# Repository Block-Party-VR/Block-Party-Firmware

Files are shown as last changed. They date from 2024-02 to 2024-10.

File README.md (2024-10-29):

# Block Party

Stack blocks in real life. See them stack in VR.
Play with blocks in VR. See them change in real life.
If you’re feeling brave, enter the doll house.

Virtual reality can be a powerful tool to connect the physical world and the digital world and connect people in different locations.
However, many VR experiences today are limited to the digital world.
Many multi-user VR experiences place all users into the same digital world and people in the VR headset are cut off from the physical world.

Block Party uses an asymmetric experience to connect a person using a VR headset with a person without a headset.
The person without a headset interacts with physical blocks on a physical board while the person in the VR headset interacts with digital blocks on a digital board.
When the physical user places a physical block on the physical board, the VR user sees a block in the corresponding location on the digital board.
When the physical user removes a block from the board, the corresponding digital block disappears for the VR user.
When the VR user hovers over or picks up a digital cube, the corresponding physical cube changes color to show the physical user what the VR user is doing.

## Setup
### Repository Setup
When the repository is first cloned you will need to initialize all of its submodules. 

In the terminal type: `git submodule update --init --recursive` which will initalize all of the submodules.

### Board Assemble
#### Parts List
- Foam core (scavenged)
- (4) Thor labs boxes (scavenged)
- (1) ESP32
- (1) breadboard
- copper tape
- (9) magnets
- (9) 10k resistors
board documentation can be found int he `documentation` directory.

### Cube Assembly
#### Parts List
- 3D printed case and cover (stl files are in the documentation folder)
- WS2812B LED (1 strip of 2 LEDs)
- (1) 10k resistor
- copper tape
- (2) magnets
- Kapton tape
- black electrical tape to mark the bottom
wiring diagram for the cube is in the `documentation` directory.

### Hardware Required
- Meta Quest headset. The included Unity project uses SDKs for Android so other Android-based headsets may work, but have not been tested.
- The physical board and physical blocks
- Two USB power sources to run the physical board. One for the LEDs and one for the sensors detecting where the blocks are.

### Software Dependencies
#### Unity
- [`the Singularity`](https://github.com/VRatMIT/TheSingularity-Unity)
- Meta Presence Platform: hand tracking, pokable item, interaction, hand-poke interaction, synthetic hands, grab interaction, hand-poke limiter, pass-through
- Unity package: [DOTween](https://assetstore.unity.com/packages/tools/animation/dotween-hotween-v2-27676)

#### Board
- Adafruit’s Neopixel library
- Arduino libraries

### Bluetooth Module
On v0.1 of the board, a seperate bluetooth module (HC-05) is being used for bluetooth. This module needs to be programmed when first plugged in. To program the module, disconnect it from power and hold the "EN" button on the module. (The button should be the only button on the HC-05 module). While still holding down the button, reconnect the module to the ESP32. Let go of the button and then press the ESP32's reset button. Wait 5 seconds while still holding down the "EN" button on the module, then release the button, power cycle the module, and you're done.

## Run
- Power up the board and pair it with the headset over bluetooth.
- Build and load the Unity project to the headset.
- The first time the Unity project starts on the headset, you will receive a request for Bluetooth permissions. Grant the permission and restart the app. The restart is required after permissions are granted due to current limitations on `the Singularity`.
- After restarting the app, the app should automatically connect to the physical board and respond to blocks being placed on the physical board.
- Enjoy the connection between the digital and physical world.

## Unity interactions

### Interacting with the digital blocks
Once the cube has been placed on the board a cube in VR will appear.
The VR user can poke and pickup the digital blocks which will be indicated in real life by changing the colors of the blocks. Poking will change the block color to blue and picking it up will change it to red.

### Passthrough mode
The user can activate passthrough mode inside the app to see the physical board and the digital board at the same time.

### Dollhouse mode
When the dollhouse mode is activated, the digital blocks are increased in size and the VR user is moved to the center square of the board.
Note that a physical cube on the center square of the board will not appear in the digital world.

## Board Command Docs
The board contains an ESP32 that uses bluetooth serial to send the state of the board and receive commands.

### Command Name: `BoardState`
Command Number: `0`

Format Example: `!0,X1,X2,X3,X4,X5,X6,X7,X8,X9;`

Description: This command is sent when the board state changes and describes how the board is populated.

| X1 X2 X3 |

| X4 X5 X6 |

| X7 X8 X9 |

0 corresponds with the command type. The command number for BoardState is 0.
X1 corresponds with board spot X1, and so on. The value in each of the spots indicates how many cubes are in that spot.
IE: If X1 where 3, then there would be 3 cubes in the top left spot.

If you would like to get the board state, you can send !0; to the ESP32 and it will respond with the current board state. Otherwise, the ESP32 will send the board state whenever it changes.

### Command Name `Ping`
Command Number: `1`

Format Example: `!1;`

Description: This command is sent to the ESP32 to check if it is still connected. The ESP32 will respond with `!1;` if it is still connected.

### Command Name: `SetStackColor`
Command Number: `2`

Format Example: `!2,StackNumber,Red1,Green1,Blue1,Red2,Green2,Blue2,...REDX,GREENX,BLUEX;`

Description Set the colors for one of the stacks.
- 2 corresponds with the command type. The command number for SetStackColor is 2.
- StackNumber corresponds with the stack number you want to set the colors for. See `BoardState` description for stack numbers.
- Red1, Green1, Blue1 correspond with the color of the first cube in the stack and so on. These values can be between 0-255.
You can add as many colors as you want, but they wont display if the corresponding cube doesn't physically exist.

### Command Name: `GoToIdle`
Command Number: `3`

Format Example `!3;`

Description: This command will tell the ESP32 to re-enable its idle animation. It will respond with a `!3;` when it recieves this command.

## Shout-Outs
- Thank you to all the organizers at Reality Hack and the Hardware track.
- Lucas De Bonet for creating `the Singularity` which allowed us to connect the board to Quest headsets.
- Mentor Mark Steelman for showing us the value (and complications) of runtime list creation and showing us how to make an in-editor button for debugging.
- Fellow Reality Hack hacker Sean Feeser for help with debugging.
- Juan Gil for helping us 3D print.

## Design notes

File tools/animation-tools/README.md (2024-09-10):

# Setup
In order to run this tool follow these steps:

1. ensure you're using python 3.12+. You can verify this by running 
```
python --version
``` 
in a terminal.

2. Inside of a terminal in the 
```
tools/animation-tools
``` 
folder, run: 
```
python -m venv venv
```
 to create your virtual environment.

3. Now activate the virtual environment. In powershell run 
```
venv\Scripts\activate
```
You may need to fix permission issues if this is your first time using a virtual environment. For git bash just run: 
```
source venv/Scripts/activate
```
4. Run 
```
pip install -r requirements.txt
```

# How to Use
The animation tool was made to allow anyone to easily create animaitons without much practice. You can create a sequence of frames in the studio, export them and then copy them over to the firmware

## Creating a Frame
When you first run the program the window will look like this:

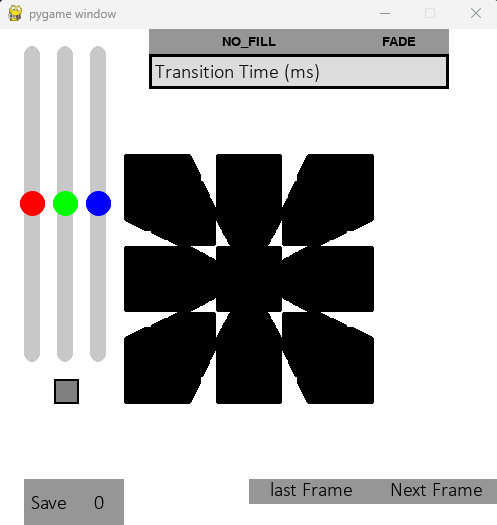
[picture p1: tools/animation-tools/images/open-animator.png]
Startup


### Rotating the view
Press and hold the middle mouse button and move around the mouse to rotate the view.

### Changing Cube Colors
Click on a cube to select it. Selected cubes will be highlighted in red. All selected cubes will be set to the current color picker color. You can deselect a block by clicking on it again.

The color picker consists of 3 sliders on the left of the screen. A preview of the color is in a small box underneath the sliders. Move the sliders around to change colors.

### Fill Options
Fill options tell the board how to color cubes which are set to black in the animator. There are four options:

#### No Fill
Cubes that are set to black will be off

#### Closest Color
Cubes that are set to black will become the same color as their closest colored neighbor

#### Linear
Cubes that are set to black will become a distance weighted average of all of the colored cubes

#### Square
Same as linear, but the distance weighting is squared. This means a cube that's twice as far away will have only 1/4 the effect.

### Fade options
The fade options tell the board how to transition between frames

#### Snap
The colors will remain constant until the delay time for the current frame has passed. At that point, the frame will immediatly switch to the next frame.

#### Fade
The colors will linearly transition from one frame to the next. This often results in very interesting colors and patterns emerging.

### Creating more than one frame
An animation isn't really an animation with only one frame. You can add more frames to your animation with the "Next Frame" button. This will create a new frame for you to edit. You'll also notice the frame counter above the next frame button will go up. That shows you the current frame number that you're editing. You can view previous frames but clicking on the last frame button.

### Exporting your Animation
Now that you're done creating your lovely animation you can export it! Click the save button and C++ code will automatically be generated which describes all of the frames you just created. The code is saved in output.txt in the animation-tools folder. How to use that code is beyond the scope of this README. Reach out to Quinn for more instruction.

# Future features
Eventually I would like to add the ability to send the animations directly to the board without having to mess with the firmware at all. This will take a pretty big rework though.

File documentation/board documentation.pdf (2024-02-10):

# Block Party by Platypods

# electrical and mechanical initial design

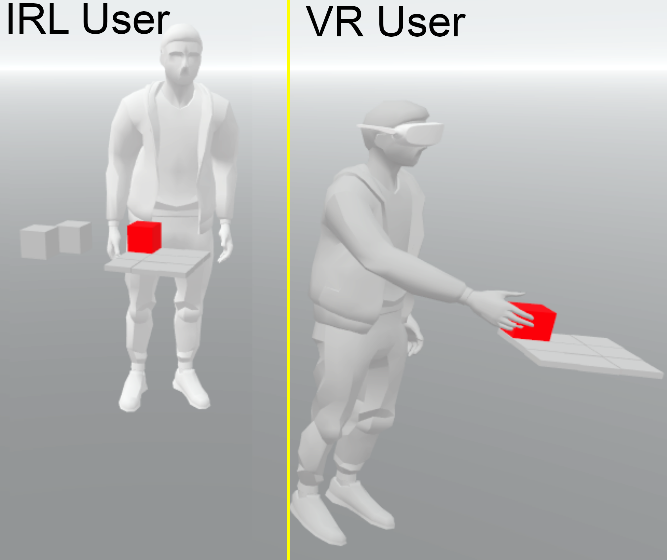
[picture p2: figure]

### Enables people in both VR and IRL to interact simultaneously with

real world objects and digital twin VR objects.

The functional idea is: to have a grid of 3x3, and use resistors to sense where blocks

populate the board, with stacked blocks reducing measured resistance. The leds

inside the blocks are addressable by the ESP32, so they may light up in IRL when

manipulated in VR.

The ESP32 sends and receives data via the MIT developed Singularity plugin for

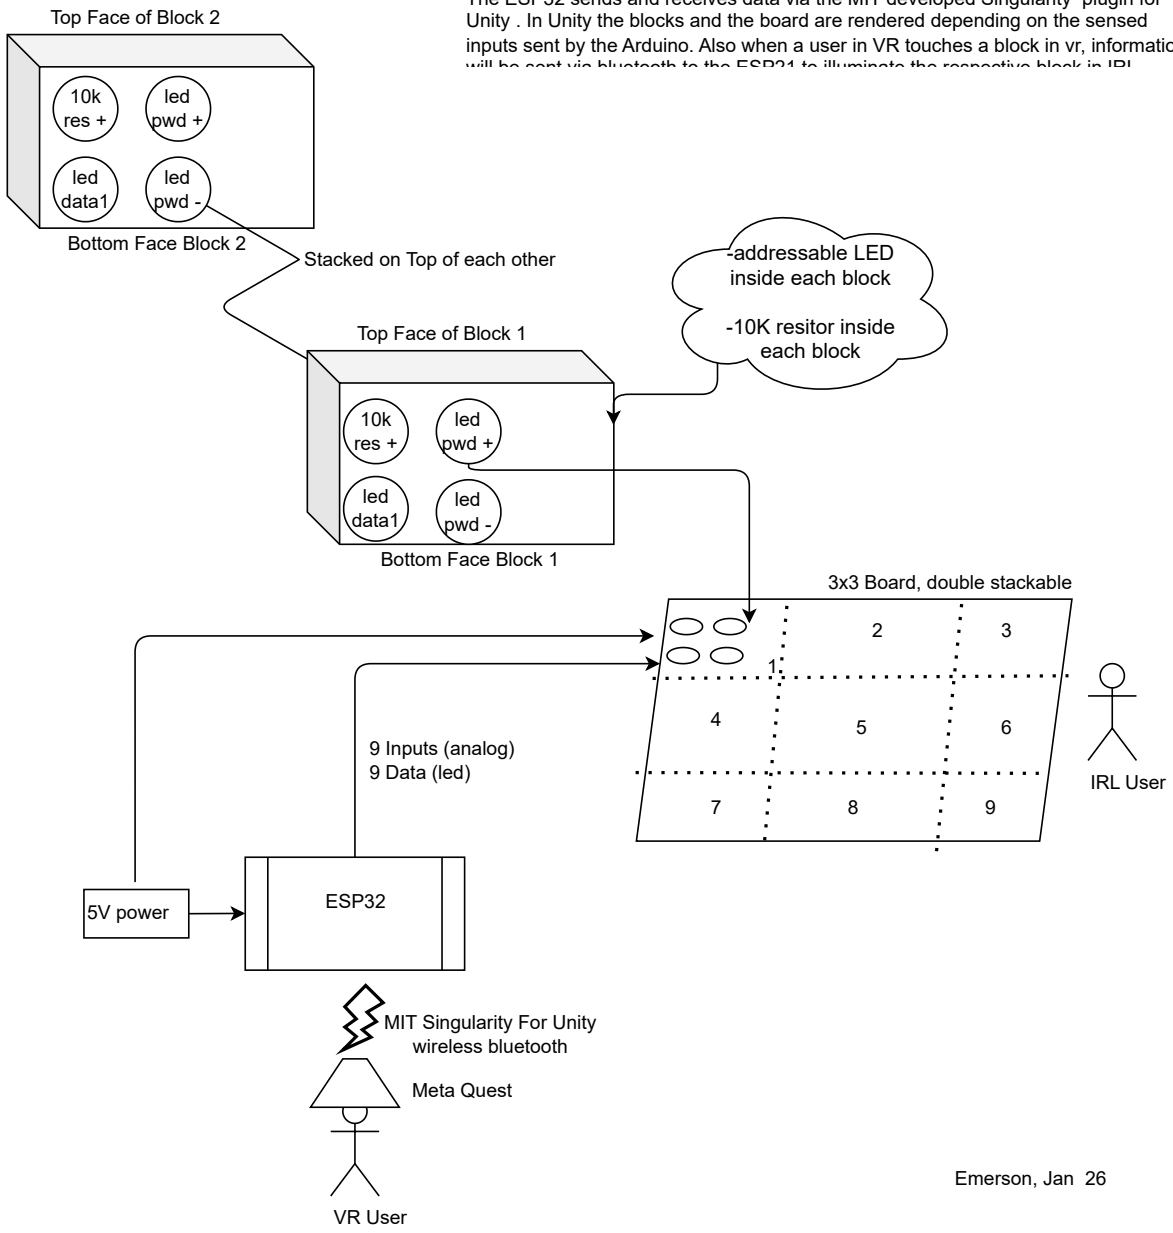
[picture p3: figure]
10k res +; led pwd +; led data1; led pwd -; Bottom Face Block 1; Top Face of Block 1; Bottom Face Block 2; Top Face of Block 2; Stacked on Top of each other; ESP32; 9 Inputs (analog) 9 Data (led); 3x3 Board, double stackable; MIT Singularity For Unity wireless bluetooth; VR User; Meta Quest; Emerson, Jan 26; 5V power; IRL User; -addressable LED inside each block; -10K resitor inside each block

Unity . In Unity the blocks and the board are rendered depending on the sensed inputs sent by the Arduino. Also when a user in VR touches a block in vr, information will be sent via bluetooth to the ESP21 to illuminate the respective block in IRL

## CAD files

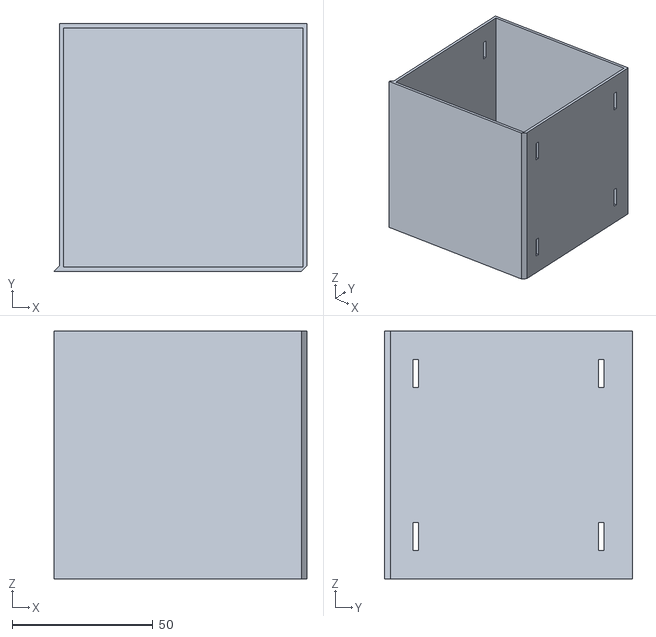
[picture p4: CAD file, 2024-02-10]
documentation/stack cube.stl
89.9 x 88.0 x 88.0

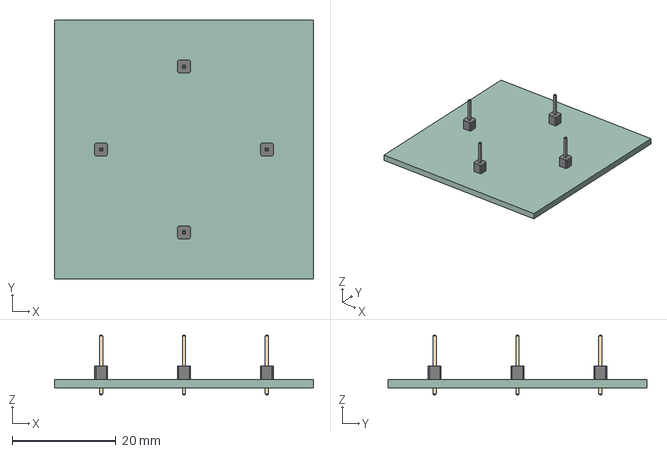
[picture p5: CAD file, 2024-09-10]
Schematics/Block-Party/PCB Models/Block-Party-Cube-Top-Board.step
50.0 x 50.0 x 11.5 mm
PinHeader_1x01_P254mm_Vertical x 4
Block-Party-Cube-Top-Board PCB

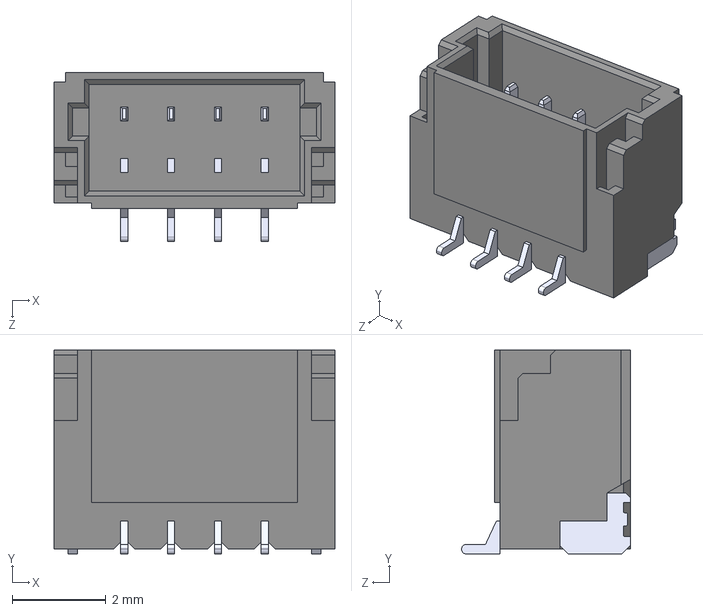
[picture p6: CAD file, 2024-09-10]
Schematics/PCB Components/adafruit-jst-4328/4328.step
6.00 x 4.35 x 3.60 mm

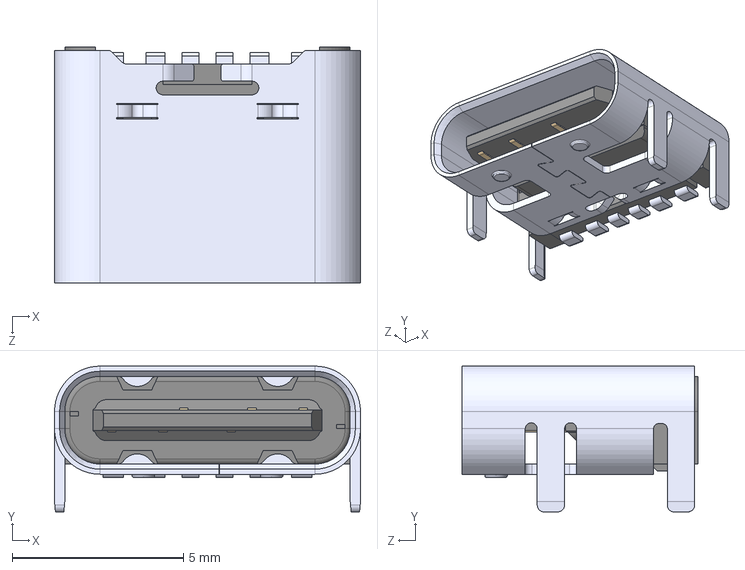
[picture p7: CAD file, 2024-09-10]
Schematics/PCB Components/UJC-HP-3-SMT-TR/UJC-HP-3-SMT-TR.step
8.94 x 4.26 x 6.90 mm

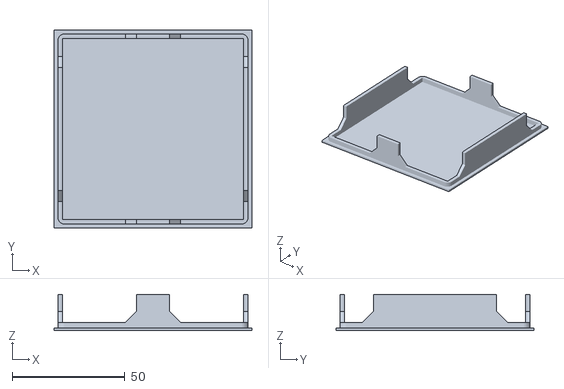
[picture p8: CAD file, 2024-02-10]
documentation/Stack_Cube_Lid.stl
88.0 x 88.0 x 16.1

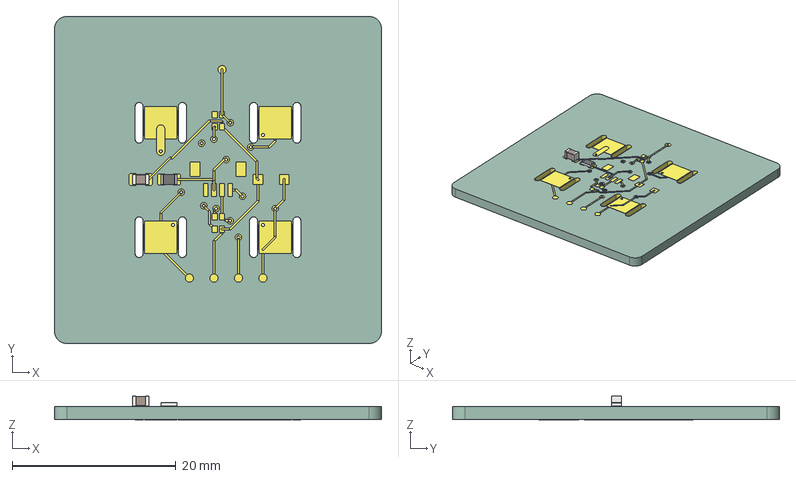
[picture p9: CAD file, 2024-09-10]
Schematics/Block-Party/PCB Models/Block-Party-Bottom-PCB.step
40.0 x 40.0 x 2.94 mm
C_0805_2012Metric
R_0805_2012Metric
Block-Party-Bottom-Board_track_1
Block-Party-Bottom-Board_track_2
Block-Party-Bottom-Board_track_3
Block-Party-Bottom-Board_track_4
Block-Party-Bottom-Board_track_5
Block-Party-Bottom-Board_track_6
Block-Party-Bottom-Board_track_7
Block-Party-Bottom-Board_track_8
Block-Party-Bottom-Board_track_9
Block-Party-Bottom-Board_track_10
Block-Party-Bottom-Board_track_11
Block-Party-Bottom-Board_track_12
Block-Party-Bottom-Board_track_13
Block-Party-Bottom-Board_track_14
Block-Party-Bottom-Board_track_15
Block-Party-Bottom-Board_track_16
Block-Party-Bottom-Board_track_17
Block-Party-Bottom-Board_track_18
Block-Party-Bottom-Board_track_19
Block-Party-Bottom-Board_track_20
Block-Party-Bottom-Board_track_21
Block-Party-Bottom-Board_track_22
Block-Party-Bottom-Board_track_23
Block-Party-Bottom-Board_track_24
Block-Party-Bottom-Board_track_25
Block-Party-Bottom-Board_track_26
Block-Party-Bottom-Board_track_27
Block-Party-Bottom-Board_track_28
Block-Party-Bottom-Board_track_29
Block-Party-Bottom-Board_track_30
Block-Party-Bottom-Board_track_31
Block-Party-Bottom-Board_track_32
Block-Party-Bottom-Board_track_33
Block-Party-Bottom-Board_track_34
Block-Party-Bottom-Board_track_35
Block-Party-Bottom-Board_track_36
Block-Party-Bottom-Board_track_37
Block-Party-Bottom-Board_track_38
Block-Party-Bottom-Board_track_39
Block-Party-Bottom-Board_track_40
Block-Party-Bottom-Board_track_41
Block-Party-Bottom-Board_track_42
Block-Party-Bottom-Board_track_43
Block-Party-Bottom-Board_track_44
Block-Party-Bottom-Board_track_45
Block-Party-Bottom-Board_track_46
Block-Party-Bottom-Board_track_47
Block-Party-Bottom-Board_track_48
Block-Party-Bottom-Board_track_49
Block-Party-Bottom-Board_track_50
Block-Party-Bottom-Board_track_51
Block-Party-Bottom-Board_track_52
Block-Party-Bottom-Board_track_53
Block-Party-Bottom-Board_track_54
Block-Party-Bottom-Board_track_55
Block-Party-Bottom-Board_track_56
Block-Party-Bottom-Board_track_57
Block-Party-Bottom-Board_track_58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

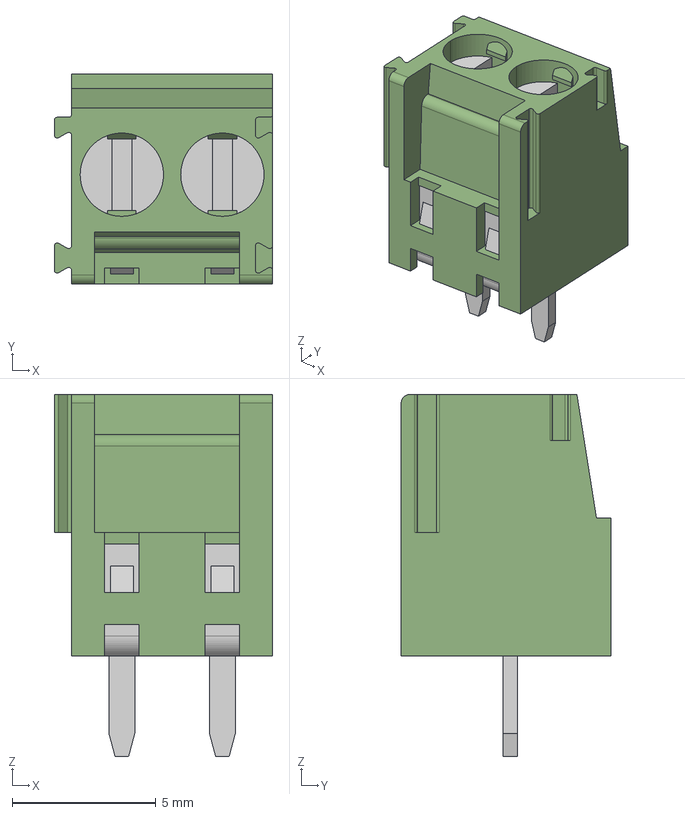
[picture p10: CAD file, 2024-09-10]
Schematics/PCB Components/2p 3.5mm terminal block/691214110002S.step
7.60 x 7.30 x 12.6 mm

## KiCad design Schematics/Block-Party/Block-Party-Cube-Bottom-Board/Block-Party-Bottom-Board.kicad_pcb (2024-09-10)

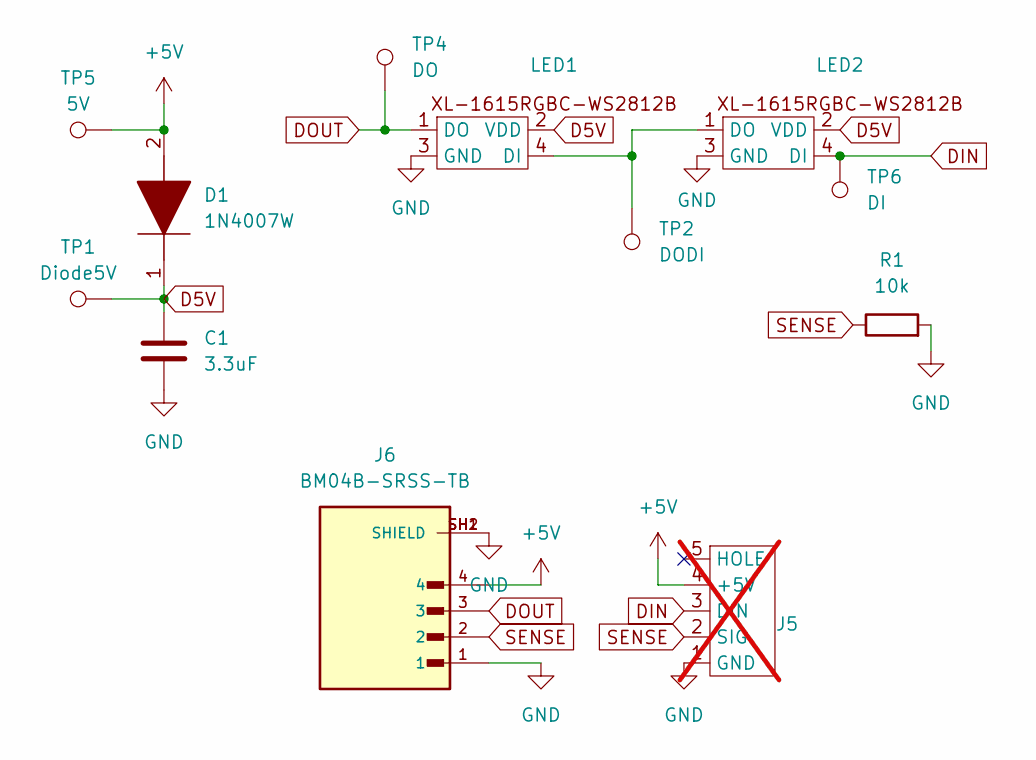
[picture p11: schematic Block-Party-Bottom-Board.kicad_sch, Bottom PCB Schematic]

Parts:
C1: 3.3uF; C_0805_2012Metric; Manufacturer_Part_Number CS2012X5R475K500NRE
D1: 1N4007W; Manufacturer_Part_Number 1N4007W
J5: Bottom Block Connector; not fitted
J6: BM04B-SRSS-TB; ADAFRUIT_4328; PARTREV 23/3/21
LED1: XL-1615RGBC-WS2812B; Manufacturer_Part_Number Quinn_lib:XL-1615RGBC-WS2812B
LED2: XL-1615RGBC-WS2812B; Manufacturer_Part_Number XINGLIGHT XL-1615RGBC-WS2812B
R1: 10k; R_0805_2012Metric; Manufacturer_Part_Number AC0805FR-0710KL
TP1: Diode5V; TestPoint_Pad_D1.0mm
TP2: DODI; TestPoint_Pad_D1.0mm
TP4: DO; TestPoint_Pad_D1.0mm
TP5: 5V; TestPoint_Pad_D1.0mm
TP6: DI; TestPoint_Pad_D1.0mm

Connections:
+5V: D1.2, J5.4 (+5V), J6.4, TP5.1
D5V: C1.1, D1.1, LED1.2 (VDD), LED2.2 (VDD), TP1.1
DIN: J5.3 (DIN), LED2.4 (DI), TP6.1
DOUT: J6.3, LED1.1 (DO), TP4.1
GND: C1.2, J5.1 (GND), J6.1, J6.SH1 (SHIELD), J6.SH2 (SHIELD), LED1.3 (GND), LED2.3 (GND), R1.2
unnamed: LED1.4 (DI), LED2.1 (DO), TP2.1
SENSE: J5.2 (SIG), J6.2, R1.1

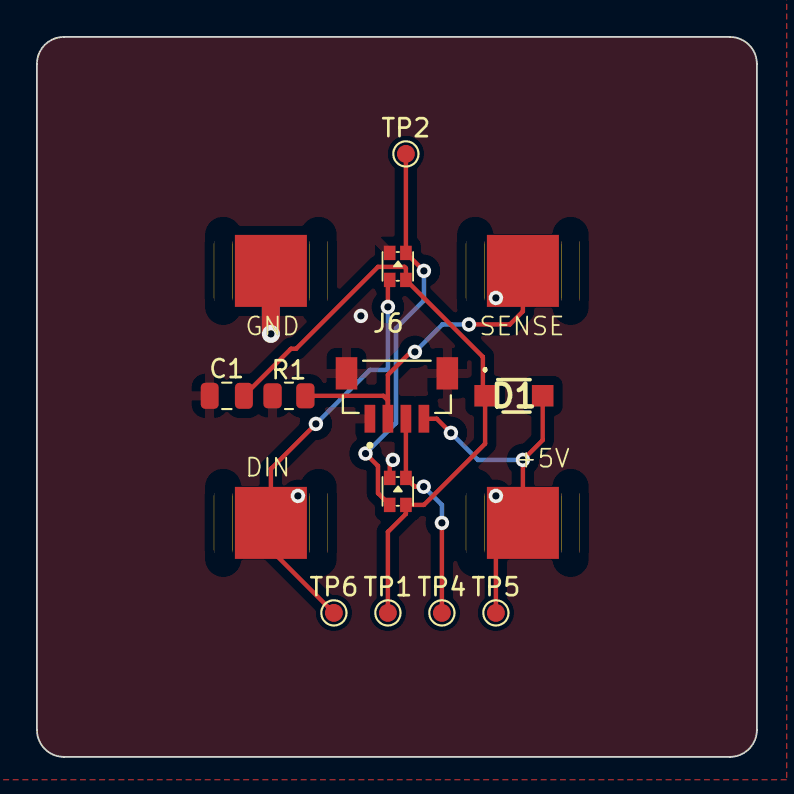
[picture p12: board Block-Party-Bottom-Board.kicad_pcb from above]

Board: 2 copper layers, 40.0 x 40.0 mm, 12 parts (0 on the bottom side), 7 nets.

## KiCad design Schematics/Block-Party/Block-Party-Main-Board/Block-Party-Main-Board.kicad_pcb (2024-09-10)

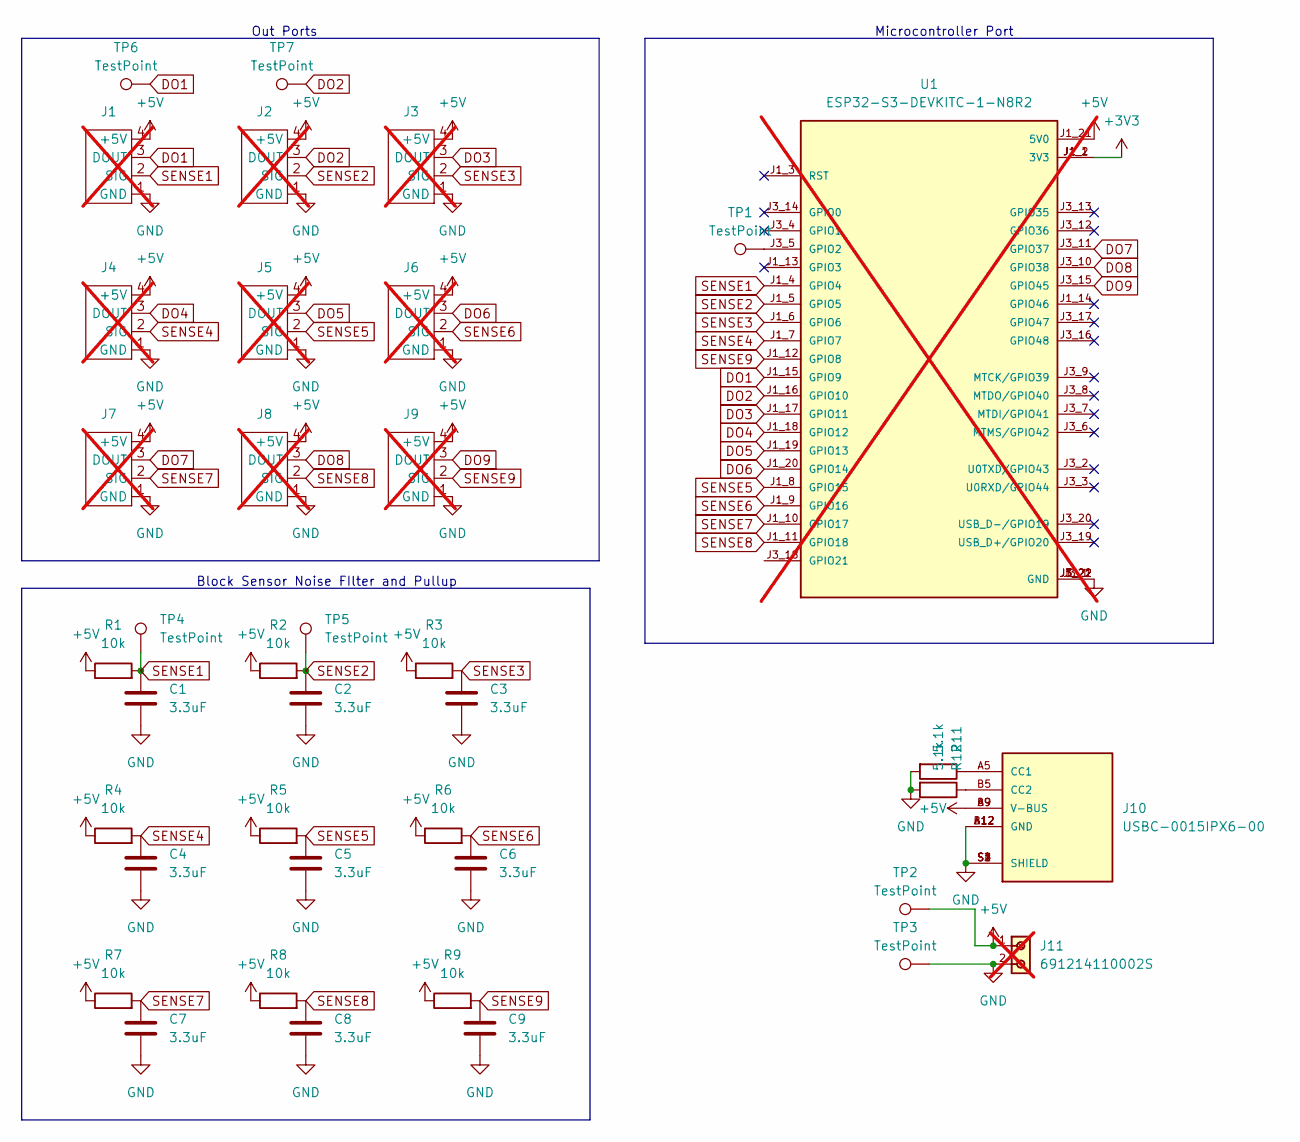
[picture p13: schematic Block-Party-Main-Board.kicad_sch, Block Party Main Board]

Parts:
C1, C2, C3, C4, C5, C6, C7, C8, C9: 3.3uF; C_0805_2012Metric; PART-NUMBER CS2012X5R475K500NRE
J1, J2, J3, J4, J5, J6, J7, J8, J9: Top Block Connector; not fitted
J10: USBC-0015IPX6-00; USB_C-0015IPX6-00; PARTREV 04/30/2020
J11: 691214110002S; PART-NUMBER 691214110002S; not fitted
R1, R2, R3, R4, R5, R6, R7, R8, R9: 10k; R_0805_2012Metric; PART-NUMBER AR05DTD1002
R11, R12: 5.1k; R_0805_2012Metric; PART-NUMBER CR0805-FX-5101ELF
TP1, TP2, TP3, TP4, TP5, TP6, TP7: TestPoint; TestPoint_Pad_D2.0mm
U1: ESP32-S3-DEVKITC-1-N8R2; XCVR_ESP32-S3-DEVKITC-1-N8R2; PARTREV V1; not fitted

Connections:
+3V3: U1.J1_1 (3V3), U1.J1_2 (3V3)
+5V: J1.4 (+5V), J2.4 (+5V), J3.4 (+5V), J4.4 (+5V), J5.4 (+5V), J6.4 (+5V), J7.4 (+5V), J8.4 (+5V), J9.4 (+5V), J10.A9 (V-BUS), J10.B9 (V-BUS), J11.1, R1.1, R2.1, R3.1, R4.1, R5.1, R6.1, R7.1, R8.1, R9.1, TP2.1, U1.J1_21 (5V0)
DO1: J1.3 (DOUT), TP6.1, U1.J1_15 (GPIO9)
DO2: J2.3 (DOUT), TP7.1, U1.J1_16 (GPIO10)
DO3: J3.3 (DOUT), U1.J1_17 (GPIO11)
DO4: J4.3 (DOUT), U1.J1_18 (GPIO12)
DO5: J5.3 (DOUT), U1.J1_19 (GPIO13)
DO6: J6.3 (DOUT), U1.J1_20 (GPIO14)
DO7: J7.3 (DOUT), U1.J3_11 (GPIO37)
DO8: J8.3 (DOUT), U1.J3_10 (GPIO38)
DO9: J9.3 (DOUT), U1.J3_15 (GPIO45)
GND: C1.1, C2.1, C3.1, C4.1, C5.1, C6.1, C7.1, C8.1, C9.1, J1.1 (GND), J2.1 (GND), J3.1 (GND), J4.1 (GND), J5.1 (GND), J6.1 (GND), J7.1 (GND), J8.1 (GND), J9.1 (GND), J10.A12 (GND), J10.B12 (GND), J10.S1 (SHIELD), J10.S2 (SHIELD), J10.S3 (SHIELD), J10.S4 (SHIELD), J11.2, R11.2, R12.2, TP3.1, U1.J1_22 (GND), U1.J3_1 (GND), U1.J3_21 (GND), U1.J3_22 (GND)
unnamed: J10.A5 (CC1), R11.1
unnamed: J10.B5 (CC2), R12.1
unnamed: TP1.1, U1.J3_5 (GPIO2)
SENSE1: C1.2, J1.2 (SIG), R1.2, TP4.1, U1.J1_4 (GPIO4)
SENSE2: C2.2, J2.2 (SIG), R2.2, TP5.1, U1.J1_5 (GPIO5)
SENSE3: C3.2, J3.2 (SIG), R3.2, U1.J1_6 (GPIO6)
SENSE4: C4.2, J4.2 (SIG), R4.2, U1.J1_7 (GPIO7)
SENSE5: C5.2, J5.2 (SIG), R5.2, U1.J1_8 (GPIO15)
SENSE6: C6.2, J6.2 (SIG), R6.2, U1.J1_9 (GPIO16)
SENSE7: C7.2, J7.2 (SIG), R7.2, U1.J1_10 (GPIO17)
SENSE8: C8.2, J8.2 (SIG), R8.2, U1.J1_11 (GPIO18)
SENSE9: C9.2, J9.2 (SIG), R9.2, U1.J1_12 (GPIO8)

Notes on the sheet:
Out Ports
Microcontroller Port
Block Sensor Noise FIlter and Pullup

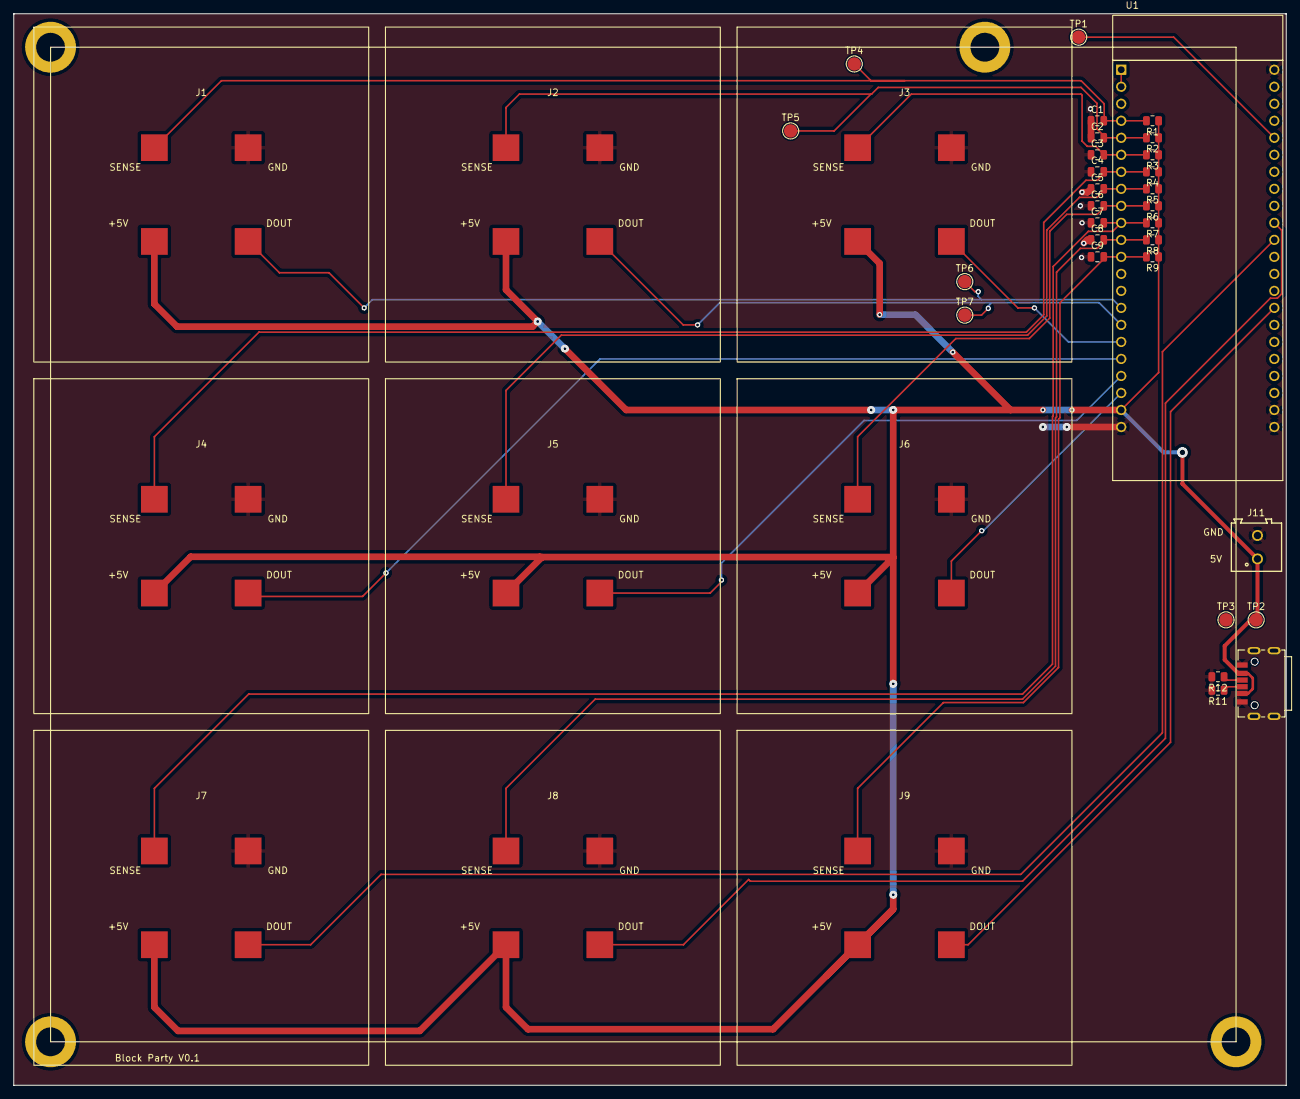
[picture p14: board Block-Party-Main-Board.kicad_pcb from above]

Board: 2 copper layers, 190.0 x 160.0 mm, 39 parts (0 on the bottom side), 24 nets.

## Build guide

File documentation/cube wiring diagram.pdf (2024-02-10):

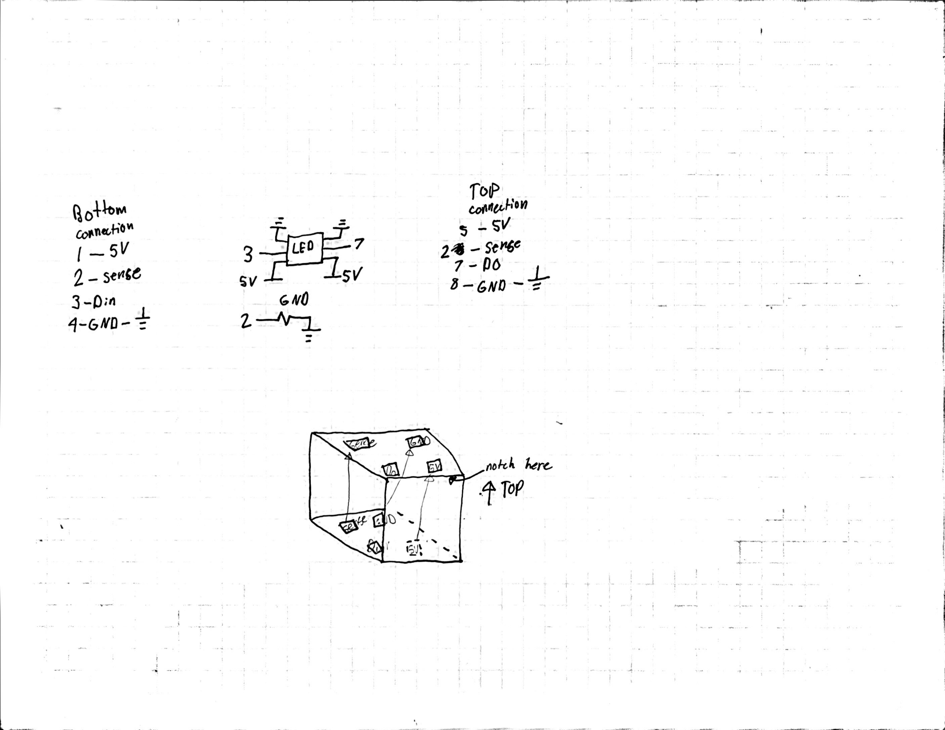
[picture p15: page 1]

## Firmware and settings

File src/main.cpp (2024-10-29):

// Other peoples libraries
#include <Arduino.h>
#include <BluetoothSerial.h>
#include <FreeRTOS.h>
#include <Adafruit_NeoPixel.h>
#include <chrono>
#include <array>

// Static Defines
#include "PINOUT.h"
#include "BOARD-DEFINITIONS.h"
#include "COMMANDS.h"

// project specific libraries
#include "BluetoothSerial.h"
#include "SerialMessage.h"
#include "GlobalPrint.h"
#include "CommandHandler.h"

#include "BoardManager.h"
#include "BoardDriver.h"
#include "BoardTypes.h"

#include "Animator.h"
#include "TestFrames.h"
#include "Animation.h"

// --------------------------------------------------
// ----------------- VARIABLES ----------------------
// --------------------------------------------------
TaskHandle_t updateCommunicaitonTask;
TaskHandle_t updateBoardTask;

// WARNING! This array size should always be equal to the number of entries in it!!
std::array<std::vector<AnimationFrame>*, 2> animations = {
  &RisingCubes::rising,
  &RotatingCubes::rotating,
};

CommandHandler commandHandler{};

// BluetoothSerial SerialBT;
// BluetoothSerialMessage serialMessageBT(&SerialBT);
SerialMessage<SERIAL_CHAR_LENGTH, SERIAL_ARG_LENGTH> serialMessage(&Serial);

Adafruit_NeoPixel pixelController{BOARD_HEIGHT*2, STACK1_LED_PIN, NEO_GRB + NEO_KHZ800};

Animator<BOARD_DIMENSIONS> animator{};
BoardDriver<BOARD_WIDTH*BOARD_LENGTH> boardDriver{stacks, pixelController};
BoardManager<BOARD_DIMENSIONS> boardManager{boardDriver, animator};
// --------------------------------------------------
// ----------------- FUNCTIONS ----------------------
// --------------------------------------------------
/**
 * @brief Send programming commands to the serial to bluetooth adapter so 
 * it is set up as expected for the VR headset
 * @post the serial baud rate will be set to 9600
 */
void SetupBluetoothModule(){
  Serial.begin(38400);
  Serial.print("AT+UART=9600,0,0\r\n"); // set baud rate to 9600
  delay(100);

  Serial.print("AT+NAME=blockPartyBT-v01\r\n"); // set name to blockPartyBT-v0.1
  delay(100);

  Serial.print("AT+PSWD=1234\r\n"); // set password to 1234
  delay(100);

  Serial.print("AT+ROLE=0\r\n"); // set to slave
  delay(100);

  // exit at mode and go into pairing mode
  Serial.print("AT+INIT\r\n");
  Serial.begin(9600);
  delay(100);
}

void printBoardState(){
  GlobalPrint::Print("!0,");
  String boardString;
  boardManager.Board2StackString(boardString);
  GlobalPrint::Print(boardString);
  GlobalPrint::Println(";");
}

void SetStackColor(uint32_t * args, uint32_t argsLength){
  uint32_t stackNum = args[0];
  uint32_t X_COORD{stackNum};
  while(X_COORD > BOARD_DIMENSIONS.x - 1){
    X_COORD -= BOARD_DIMENSIONS.x;
  }
  uint32_t Y_COORD{(stackNum - X_COORD) / BOARD_DIMENSIONS.y};
  Serial.println("StackNum: " + String(stackNum));
  Serial.println("X: " + String(X_COORD) + " Y: " + String(Y_COORD));
  uint32_t numColors = (argsLength - 1) / 3;

  // nothing to do if no colors were given
  if(numColors == 0){
    return;
  }
  
  Serial.println("Num Colors: " + String(numColors));
  V3D<uint32_t> colors[numColors];
  
  for(int i = 0; i < numColors; i++){
    uint32_t red = args[1 + (i * 3)];
    uint32_t green = args[2 + (i * 3)];
    uint32_t blue = args[3 + (i * 3)];
    colors[i] = V3D<uint32_t>{red, green, blue};
    Serial.println("Color: " + String(red) + "," + String(green) + "," + String(blue));
  }
  boardManager.SetColumnColors(V3D<uint32_t>{X_COORD, Y_COORD, BOARD_TYPES::PLANE_NORMAL::Z}, colors, numColors);
}

// command handling functions
CommandHandler::CommandStatus BoardStateCommandHandler(uint32_t * /*args*/, uint32_t /*argsLength*/){
  printBoardState();
  return CommandHandler::CommandStatus::SUCCESS;
}

CommandHandler::CommandStatus PingCommandHandler(uint32_t * /*args*/, uint32_t /*argsLength*/){
  GlobalPrint::Println("!" + String(Commands::PING) + ";");
  return CommandHandler::CommandStatus::SUCCESS;
}

CommandHandler::CommandStatus SetColorCommandHandler(uint32_t * args, uint32_t argsLength){
  GlobalPrint::Println("!2;");
  animator.isEnabled = false;
  V3D<uint32_t> black{};
  boardManager.FillColor(black);
  SetStackColor(args, argsLength);
  return CommandHandler::CommandStatus::SUCCESS;
}

CommandHandler::CommandStatus GoToIdleCommandHandler(uint32_t * /*args*/, uint32_t /*argsLength*/){
  GlobalPrint::Println("!3;");
  animator.isEnabled = true;
  return CommandHandler::CommandStatus::SUCCESS;
}



// --------------------------------------------------
// ----------------- FREERTOS TASKS -----------------
// --------------------------------------------------
void UpdateCommunication(void * params){
  Serial.println("Spawning UpdateCommunication task");
  for(;;){
    // DO serial processing
    serialMessage.Update();
    if(serialMessage.IsNewData()){
      // We reinterpret cast the args to a uint32_t pointer because we know that the args will always be positive
      commandHandler.ProcessCommand(reinterpret_cast<uint32_t *>(serialMessage.GetArgs()), serialMessage.GetPopulatedArgs());
      serialMessage.ClearNewData();
    }
    // serialMessageBT.Update();
    // if(serialMessageBT.IsNewData()){
    //   commandHandler.ProcessCommand(reinterpret_cast<uint32_t *>(serialMessage.GetArgs()), serialMessage.GetPopulatedArgs());
    //   serialMessage.ClearNewData();
    // }
    vTaskDelay(3);
  }
  Serial.println("UpdateCommunication task has ended unexpectedly!");

}

void UpdateBoard(void * params){
  Serial.println("Spawning UpdateBoard task");
  auto updateTickRate{std::chrono::milliseconds(8)};
  auto boardStateTimer{std::chrono::milliseconds(0)};
  auto boardStateMaxUpdatePeriod{std::chrono::milliseconds(34)}; // this is a little slower than 30fps
  unsigned long accurateTimer{millis()};
  auto changeAnimationTimer{std::chrono::milliseconds(0)};
  uint8_t currentAnimation{0};

  for(;;){
    auto actualTimePassed{std::chrono::milliseconds(millis() - accurateTimer)};
    accurateTimer = millis();

    if(boardStateTimer >= boardStateMaxUpdatePeriod && boardManager.HasBoardChanged()){
      printBoardState();
      boardManager.ClearBoardChanged();
      boardStateTimer = std::chrono::milliseconds(0);
    }

    if(changeAnimationTimer >= std::chrono::duration_cast<std::chrono::milliseconds>(std::chrono::minutes(1))){
      changeAnimationTimer = std::chrono::milliseconds(0);
      currentAnimation++;
      if(currentAnimation >= animations.size()){
        currentAnimation = 0;
      }
      animator.StartAnimation(animations[currentAnimation]);
    }

    animator.RunAnimation(actualTimePassed);
    boardManager.Update();

    boardStateTimer += actualTimePassed;
    changeAnimationTimer += actualTimePassed;
    vTaskDelay(updateTickRate.count());
  }
  Serial.println("UpdateBoard task has ended unexpectedly!");
}


// --------------------------------------------------
// ----------------- SETUP AND LOOP -----------------
// --------------------------------------------------

void setup() {
  // delay a little bit to get the serial monitor a chance to capture the next log messages.
  delay(1000);

  Serial.begin(9600);
  Serial.println("Beginning Setup");
  Serial.println("Configuring Bluetooth Adapter");
  SetupBluetoothModule();
  Serial.begin(9600);

  // Register all of our commands with the command handler
  commandHandler.RegisterCommand(Commands::BoardState, BoardStateCommandHandler);
  commandHandler.RegisterCommand(Commands::PING, PingCommandHandler);
  commandHandler.RegisterCommand(Commands::SetStackColors, SetColorCommandHandler);
  commandHandler.RegisterCommand(Commands::GoToIdle, GoToIdleCommandHandler);

  Serial.println("Configuring communication methods");
  serialMessage.Init(9600);
  // SerialBT.begin("blockPartyBT");
  xTaskCreate(UpdateCommunication, "UpdateCommunication", 10000, NULL, 0, &updateCommunicaitonTask);

  Serial.println("Beginning Board Initializaiton");
  boardManager.Init();
  animator.SetLoop(true);
  animator.StartAnimation(animations[0]);
  xTaskCreate(UpdateBoard, "UpdateBoard", 10000, NULL, 0, &updateBoardTask);

  Serial.println("Setup Complete");
}


void loop() {
  // delete the loop task because we don't use it
  vTaskDelete(NULL);
}

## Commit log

2024-02-10 Created bottom block schematic
    [Block-Party.kicad_pcb, Block-Party.kicad_sch]
2024-02-13 Created block party main board schematic
    [Block-Party-Main-Board.kicad_pcb, Block-Party-Main-Board.kicad_sch, Block-Party.kicad_pcb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]
2024-02-13 Added a usb power connector.
    [Block-Party-Main-Board.kicad_pcb, Block-Party-Main-Board.kicad_sch]
2024-02-13 Added additional components.
    [UJC-HP-3-SMT-TR.step]
2024-02-13 Finished touch up details for the bottom block board
    [Block-Party.kicad_pcb]
2024-02-16 Finished v1.0 of the PCBs
    [Block-Party-Bottom-PCB.step, Block-Party-Cube-Top-Board.kicad_pcb, Block-Party-Cube-Top-Board.kicad_sch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]
2024-03-23 Flipped the bottom pads to be the correct orientation
    [Block-Party.kicad_pcb]
2024-04-20 rearranged the schematic folders
    [Block-Party-Bottom-Board.kicad_pcb, Block-Party-Bottom-Board.kicad_sch]
2024-04-23 Revision 1.01 of the PCBs
    [4328.step, 691214110002S.step, Block-Party-Bottom-Board.kicad_pcb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]
2024-04-23 Found a good jst part number and updated the BOMs
    [Block-Party-Bottom-Board.kicad_pcb, Block-Party-Bottom-Board.kicad_sch, Block-Party-Cube-Top-Board.kicad_pcb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]
2024-04-29 Made the top and bottom PCB the same size
    [Block-Party-Bottom-Board.kicad_pcb, Block-Party-Cube-Top-Board.kicad_pcb]
2024-05-07 Added main board mounting holes
    [Block-Party-Main-Board.kicad_pcb]
2024-05-07 Added bottom pads to the bottom block PCB
    [Block-Party-Bottom-Board.kicad_pcb, Block-Party-Bottom-PCB.step]
2024-05-16 Updated micro configuration files to match the new micro we're using.
    [Block-Party-Bottom-Board.kicad_pcb, Block-Party-Bottom-Board.kicad_sch]
2024-06-07 Small tweaks and an update limiter for the esp32
    [Block-Party-Main-Board.kicad_pcb]
2024-06-10 Pulled the most up to date serial driver
2024-08-12 added v0.1 to the bluetooth module name
    If you have multiple bluetooth devices paired with the same name, the quest app only connects to the first one on the list. Adding the version number lets us keep multiple versions of the board paire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
2024-08-20 Added framework for users to edit the paltformio file for machine differences without uploading the changes to github.
2024-08-22 Refactoring how board control works
2024-08-23 Completed the board manager rewrite
2024-08-23 Added comments to the functions in board.h
2024-08-23 Added comments to boarddriver.h
2024-08-25 Fixed several buffer overflow issues
    [main.cpp]
2024-08-25 The board now works as expected but without idle animations
2024-08-26 minor bug fixes and a new animation
    [main.cpp]
2024-08-28 Got a single frame exporting correctly
    [main.cpp]
2024-08-28 You can now generate many consecutive frames
2024-08-29 Added a frame counter
2024-09-12 renabled a missing animation
    [main.cpp]
2024-09-25 Moved the lambdas to actual functions to avoid them dissapearing after setup.
    [main.cpp]
2024-10-29 Fixed off by one error and updated readme
    [main.cpp]
